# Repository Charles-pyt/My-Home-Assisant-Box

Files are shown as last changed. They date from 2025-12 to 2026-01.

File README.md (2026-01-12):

# My-Home-Assisant-Box

The aim of this project is to build a mini box containing a single-board computer (maybe a RaspberryPi) that can run Home Assistant and connect all your smart devices. Prebuilt Home-Assistant exists but they are expensive and  now they have stop the production of them. You can build it for  €109.26 if you already have certain tools and €125.68 if you don't have any parts.

## Parts needed

-Raspberry PI 4 Model B 2GB 

-Power Supply 15W USB-C

-ZigBee Dongle

-SD Card (16GB)

-M2.5 mm Inserts

-M2.5x5 mm Screws

-10x2 mm Magnets (glue with super glue)

-Extension cord USB-A Male to Female 0.5m

-D1 mini ESP8266

-LEDs SK6812 RGBW 5V

-Noctua NF-A4x10 40mm 5V 3PIN

# Images

# BOM (Bill of Materials)

Capture d'écran 2026-01-12 202131

## Box
Vue d'ensemble
Vue d'ensemble derriere
Vue connecteur

## Inside
Vue aeration
Vue aeration 2
Vue derriere

## Components
Vue-éclatée

# Schematic
Schéma

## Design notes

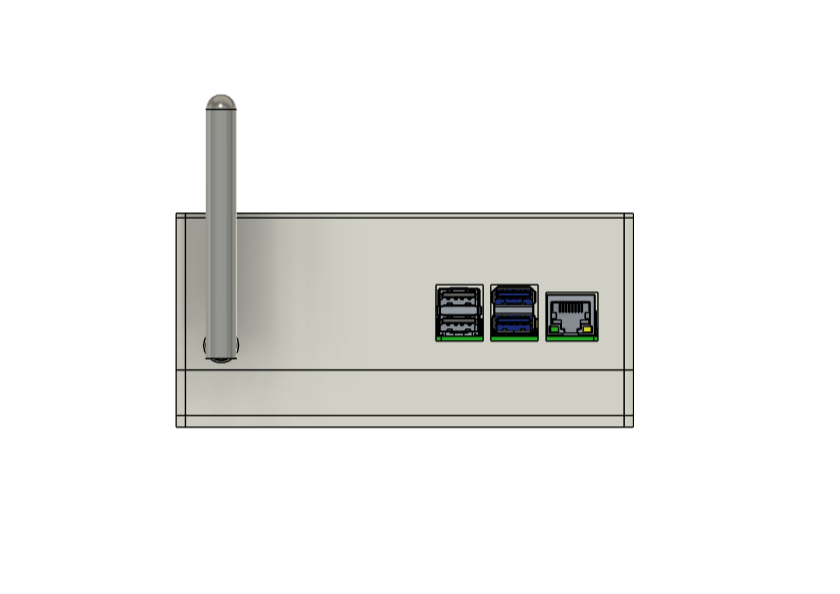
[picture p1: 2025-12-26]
images/Vue connecteur.png

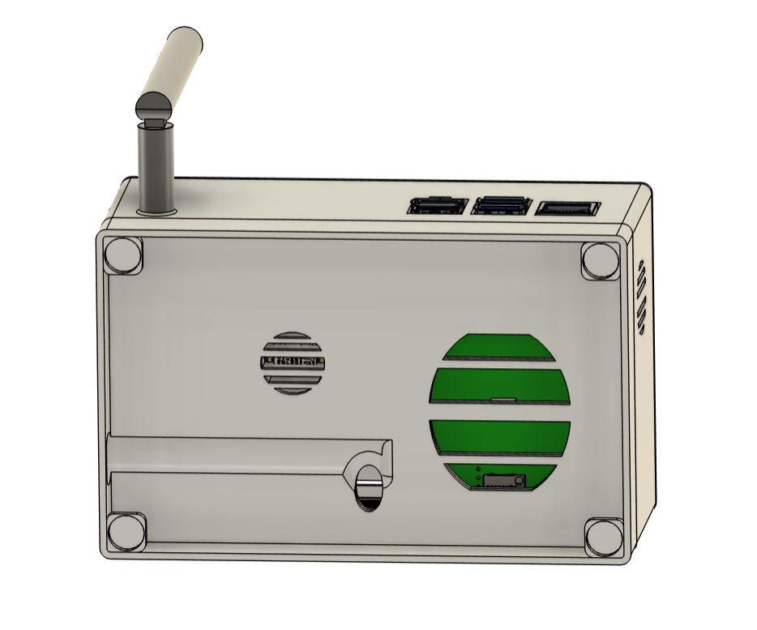
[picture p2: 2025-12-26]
images/Vue derriere.png

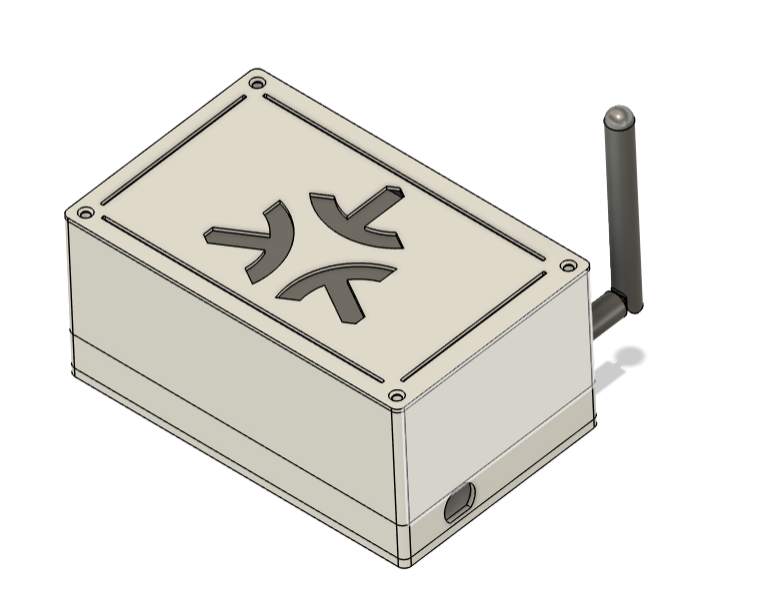
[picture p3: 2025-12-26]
images/Vue d'ensemble.png

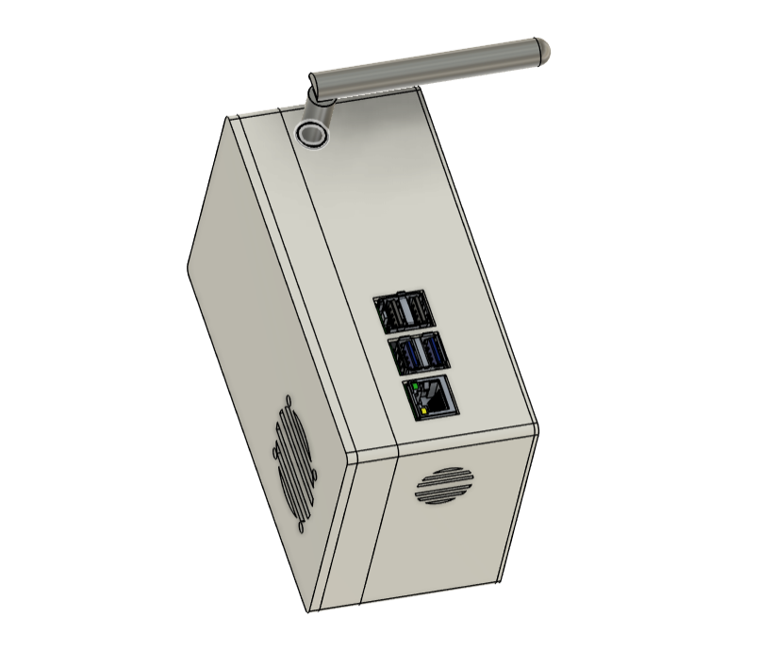
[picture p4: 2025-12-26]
images/Vue d'ensemble derriere.png

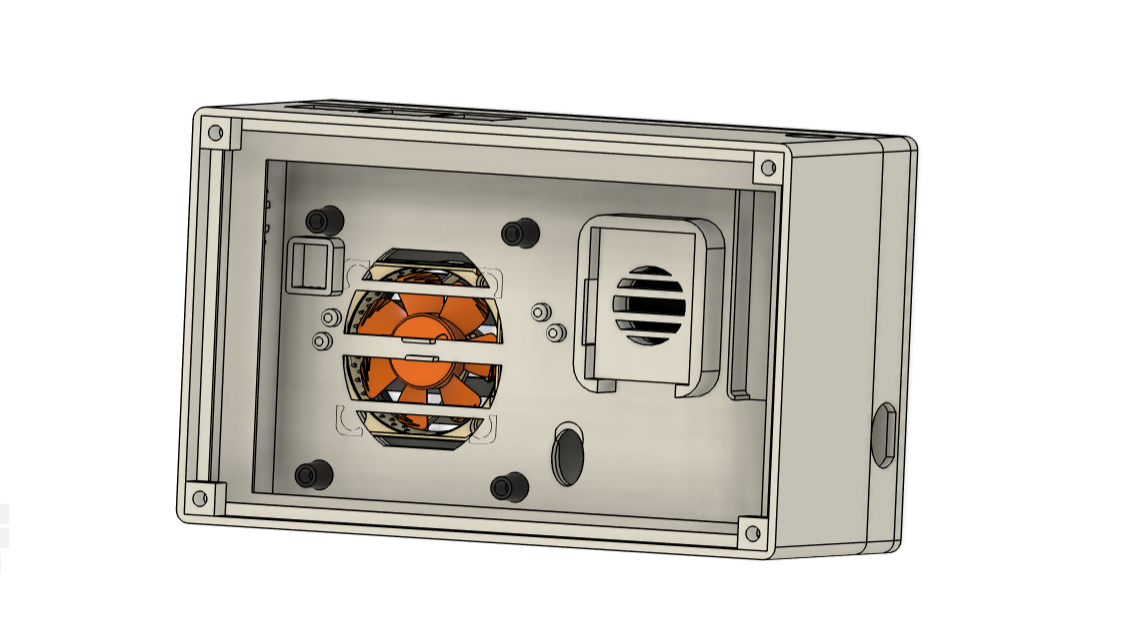
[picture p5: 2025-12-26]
images/Vue aeration 2.png

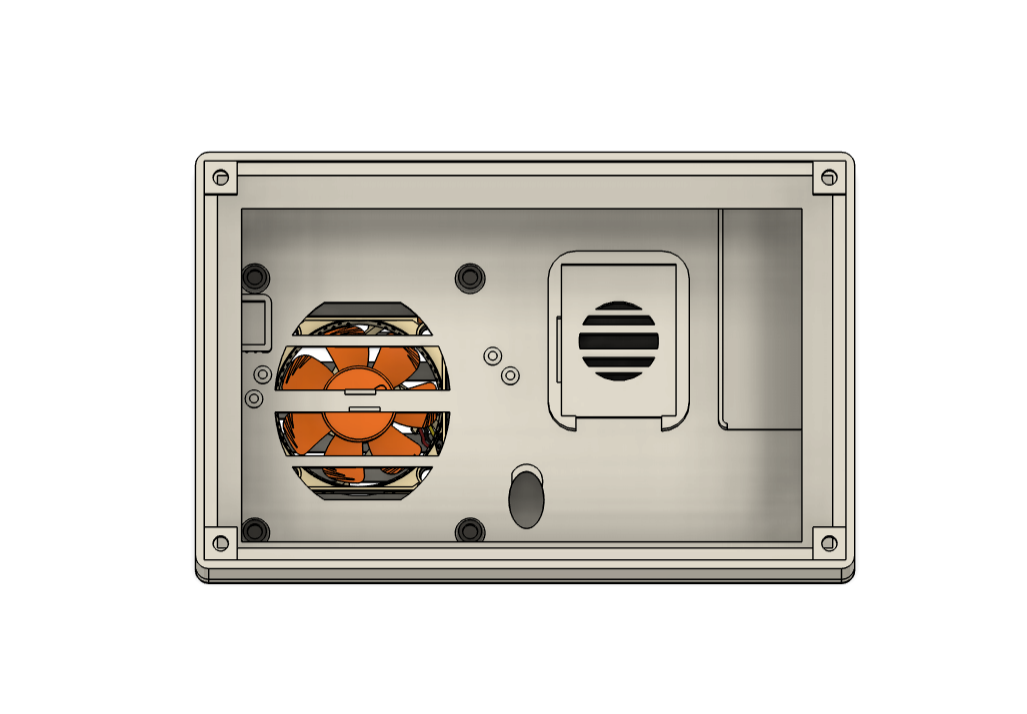
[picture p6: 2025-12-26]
images/Vue aeration.png

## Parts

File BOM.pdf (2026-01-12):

Item CountItem Name | | Description | Qty | Link / Source | Cost (in €)
1 | Raspberry Pi 4 Model B | Main Server (2GB RAM) | 1 | Raspberry Pi 4B - 2GB (https://www.kubii.com/fr/cartes-nano-ordinateurs/2771-raspberry-pi-4-modele-b-2gb-5056561800332.html) | 51,00€
2 | USB-C Power Supply | Official 15W Power Adapter | 1 | Official power supply 15W USB-C (https://www.kubii.com/fr/alimentations/2678-1049-alimentation-officielle-153w-usb-c-pour-raspberry-pi-4-400-3272496300002.html) | 6,90€
3 | ZigBee Dongle | Multiprotocol USB Stick (Matter/Zigbee) | 1 | Dongle ZigBee-E 3.0 (https://www.aliexpress.com/ssr/300000512/BundleDeals2?productIds=1005007089589385:12000039362722962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) | 20,39€
4 | Micro SD Card | 16GB Class 10 | 1 | PNY 16 Go Extreme microSDXC (https://www.amazon.fr/gp/product/B076K93GJ5?smid=A2Z84JVYM3YVET&th=1) | 11,26€
5 | D1 Mini ESP8266 | Microcontroller for WLED Control | 1 | D1 Mini TYPE-C ESP8266 ESP-12F (https://fr.aliexpress.com/item/1005007877904928.html?mp=1) | 2,28€
6 | SK6812 RGBW LED Strip | 5V Addressable LEDs | 1 | Led SK6812 RGBW, 5V (https://fr.aliexpress.com/item/32476317187.html?mp=1) | 5,79€
7 | Noctua NF-A4x10 5V | 40mm PWM Cooling Fan | 1 | Noctua NF-A4x10 40mm (https://www.amazon.fr/NF-A4X10-FLX-5V-Ventilateur-ventilateur-refroidisseur/dp/B00NEMGCIA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) | 15,90€
8 | USB-A Extension Cable | 0.5m Male to Female (Internal routing) | 1 | Extension Cable (https://www.aliexpress.com/ssr/300000512/BundleDeals2?productIds=1005005963906770:12000035123663502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) | 1,59€
9 | M2.5 Threaded Inserts | Brass inserts for case assembly | 1 pack | M2.5 Threaded Inserts (https://www.aliexpress.com/ssr/300000512/BundleDeals2?productIds=1005006351445007:12000036858180035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) | 3,79€
10 | M2.5x5mm Screws | Screws for case assembly | 1 pack | M2.5x5mm Screws (https://www.aliexpress.com/ssr/300000512/BundleDeals2?productIds=1005007345768217:12000040359433232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) | 4,59€
11 | 10x2mm Magnets | Neodymium magnets for lid | 1 pack | 10x2mm Magnets (https://www.aliexpress.com/ssr/300000512/BundleDeals2?productIds=1005009716555660:12000049936658669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) | 2,19€
12 | Custom 3D Printed Case | Self-designed PLA/PETG Enclosure | 1 | Self-made (Legion) | N/A
| | | | TOTAL | 125,68€

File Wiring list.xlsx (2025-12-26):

Source Component | Source Pin | Destination Component | Destination Pin | Function / Description
Raspberry Pi 4 (J3) | Pin 2 (5V) | Wemos D1 Mini (U1) | 5V | Microcontroller Power Supply
Raspberry Pi 4 (J3) | Pin 2 (5V) | LED Strip Connector (J2) | Pin 1 (VCC) | LED Strip Power Supply
Raspberry Pi 4 (J3) | Pin 4 (5V) | Potentiometer (RV1) | Pin 1 | Input Power for Fan Control
Raspberry Pi 4 (J3) | Pin 6 (GND) | Fan (M1) | Pin 1 (-) | Fan Ground Return
Raspberry Pi 4 (J3) | Pin 9 (GND) | Wemos D1 Mini (U1) | GND | Microcontroller Ground
Raspberry Pi 4 (J3) | Pin 9 (GND) | LED Strip Connector (J2) | Pin 3 (GND) | LED Strip Ground
Wemos D1 Mini (U1) | Pin D4 | LED Strip Connector (J2) | Pin 2 (DATA) | LED Data Signal (WLED)
Potentiometer (RV1) | Pin 2 (Wiper) | Fan (M1) | Pin 2 (+) | Variable Voltage to Fan
Notes for assembly: | Potentiometer Pin 3: Left unconnected (NC)
 | Fan Pin 3 (Tacho): Left unconnected (NC)

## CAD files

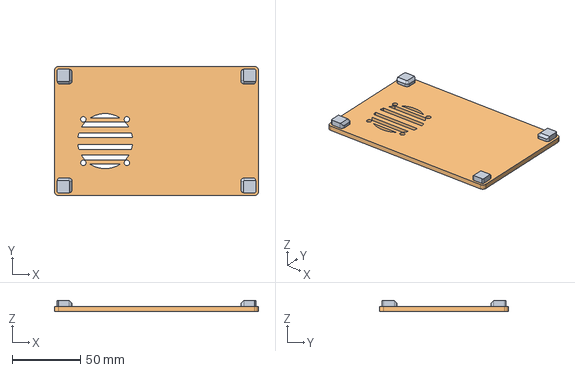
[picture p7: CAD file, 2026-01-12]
3D MODEL/STEP/BackPlate.step
150.0 x 95.0 x 8.00 mm

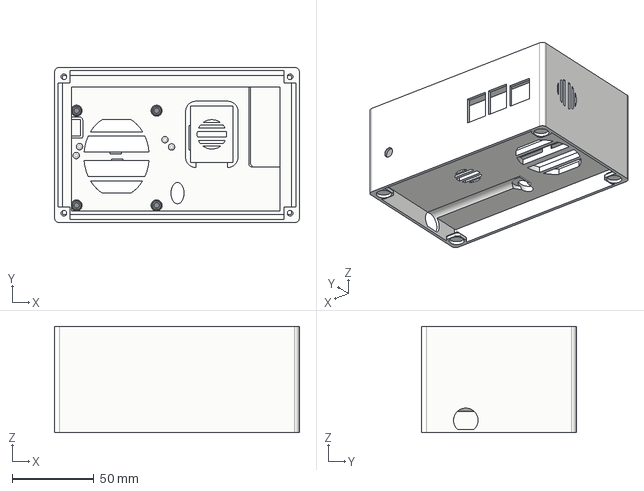
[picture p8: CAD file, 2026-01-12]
3D MODEL/STEP/Box.step
150.0 x 95.0 x 65.0 mm

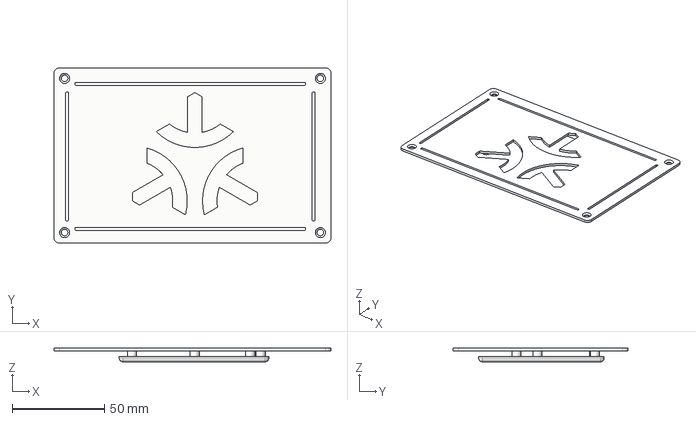
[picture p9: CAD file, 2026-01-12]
3D MODEL/STEP/Top.step
150.0 x 95.0 x 7.50 mm

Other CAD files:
3D MODEL/STL/BackPlate.stl
3D MODEL/STL/Box.stl
3D MODEL/STL/Top.stl

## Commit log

2025-12-22 Add STL models and related images for enclosure
    Added STL files for enclosure components and corresponding images for documentation and visualization. This includes back, box, cable gland, components plate, front, and front LED models, as well as 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
    [back.stl, box.stl, cable_gland.stl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]
2025-12-22 Clarify project aim and cost of building Home Assistant box
    Updated project description to clarify the use of Raspberry Pi and cost details.
2025-12-23 Add Noctua NF-A4x10 40mm fan to README
    Added Noctua NF-A4x10 fan to the components list.
2025-12-26 Update STL, schematic, and documentation files
    Added new STL files (BackPlate.stl, Top.stl), updated box.stl, and removed several old STL files. Added new schematic (Schematic.kicad_sch), BOM, and wiring list files in both PDF and XLSX formats. U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
    [BOM.xlsx, BackPlate.stl, Schematic.kicad_sch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]
2025-12-26 Add BOM section and schematic image to README
    Added a section for Bill of Materials and included a schematic image.
2025-12-26 Add BOM spreadsheet and related images
    Added BOM.xlsx and two images (BOM.png and Schéma.png) to provide documentation and visual references for the bill of materials and schematic.
    [BOM.xlsx]
2025-12-26 Update checkout images and replace Sd.png
    Added 'SD and FAN.png', removed 'Sd.png', and updated 'Style.png' in the Checkout directory. This likely reflects updated or consolidated image assets for the checkout process.
2026-01-12 Add 3D models and migrate KiCad schematics
    Added STEP files for BackPlate, Box, and Top, and moved corresponding STL files to a new directory. Migrated KiCad schematic and PCB files to a new folder structure. Updated BOM files to reflect thes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
    [BOM.xlsx, BackPlate.step, BackPlate.stl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]
2026-01-12 Update SD and FAN.png
